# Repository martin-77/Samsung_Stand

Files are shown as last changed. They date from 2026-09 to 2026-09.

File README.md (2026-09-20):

# Samsung_Stand

Parametric, test-driven CAD project for a modular PETG adapter that reuses the original Samsung UE55J6250 stand on a Magnat Sounddeck 150 and adds limited swivel.

## Design targets

- Reuse the original Samsung stand assembly.
- Magnat Sounddeck 150 footprint: **700 × 340 mm**.
- Working Samsung stand-only footprint: **840 mm width** and ~**288 mm reconstructed depth**; both remain subject to physical stand measurement. Samsung separately specifies the complete UE55J6250 **TV+stand envelope** as 1230.6 × 770.6 × 310.5 mm, which must not be confused with the stand-only footprint.
- Printer target: **Prusa CORE One L, 300 × 300 × 330 mm**.
- Material target: PETG.
- Modular printed construction with form-locking joints; snap tabs are retention only, never primary structural load paths.
- Large fixed base on the Sounddeck.
- Central swivel with limited range, initially **±15°**.
- Inner saddle/support points carry vertical load inside the Sounddeck footprint.
- Outer printed rails guide the original Samsung stand but should not become long vertical-load cantilevers.
- No CAD change is considered valid until geometry/layout checks pass.

## Engineering approach

This repository follows the test-driven CAD approach used in `martin-77/eurobox`:

1. Keep dimensional truth in code.
2. Validate global assembly geometry independently from local CAD construction.
3. Hard-gate print-bed limits, support-point position, swivel sweep, clearances and exported meshes.
4. Generate CAD/STL only from the validated parameter set.
5. Treat inferred dimensions separately from verified dimensions.

## Current baseline

Initial working geometry:

- Sounddeck: 700 × 340 mm
- Fixed base target: 680 × 295 mm
- Samsung stand width: 840 mm
- Samsung stand-only reconstructed depth: ~288 mm (unverified)
- Samsung complete TV+stand depth: 310.5 mm (manufacturer-verified envelope, not stand-only footprint)
- Pivot offset: 64 mm rearward from Sounddeck center
- Inner load/saddle stations: x ≈ ±250 mm along the reconstructed arm geometry
- Saddle orbit radius: ~279 mm
- Swivel target: −15° / 0° / +15°

See `docs/DESIGN_BASELINE.md` and the geometry validation scripts before changing these values.

## Current status

The repository has progressed to **v8** as the validated structural geometry candidate, plus a measurement-driven contact-generation pipeline:

- v1: modular three-piece fixed base and central annular swivel bearing;
- v2: dual-load-path INNER_ARM with rotor root landing and side glide tracks;
- v3: modular OUTER_GUIDE rails, intentionally non-load-bearing vertically;
- v4: calibrated positive mechanical +/-15 degree end stops plus complete carrier sweep clearance;
- v5: replaceable zero-position PETG detent cassette with 1.8 / 2.2 / 2.6 mm calibration variants;
- v7: replaceable 1.2 mm PETG center-bearing and side-track wear surfaces while preserving the validated z=10 / z=18 support planes;
- v8: fully assembled transverse PETG retention: four above-base module pins, two ROTOR/INNER pins, two externally accessible INNER/OUTER pins and one positive pivot cross-pin in a top-open rotor chamber;
- measured-contact pipeline: provenance-gated physical measurement model, three-section root/center/tip saddle lofts per side, and four independent lateral-only OUTER_GUIDE side rails;
- proof-load tooling: two flat saddle-pocket inserts that apply the 500 N structural substitute load at the validated support stations on a rigid surrogate support, not on the Sounddeck;
- release-validation pipeline: a machine-checkable physical test record that verifies the user-declared proof, creep, cycling, fit-coupon and Sounddeck-interface criteria.

For v8 the parameter gates, FreeCAD build, watertight-mesh checks and installed
OCC collision/contact checks are green. All replacement retainers are checked in
their actual installed positions. The pivot lock preserves the full +/-15 degree
rotation with 0.7 mm intentional axial lift clearance and positively blocks
further lift. The +/-15 degree end stops remain structural; the center detent is
positional only.

The v6 measurement-to-CAD path is also green against a synthetic CI fixture:
measurement validation, FreeCAD generation, watertight-mesh gates and installed
contact-part checks against the current v8 structural STEP geometry all pass.
All six measured saddle sections (left/right root/center/tip) are checked at
their exact YZ station for surface contact with **0 mm² section penetration**;
the load-bearing loft is limited to 25 mm maximum measured-section spacing and
8 mm maximum endpoint extrapolation. OUTER_GUIDE root/mid/tip profiles are
checked at 0.5 mm nominal
lateral clearance and at their measured common-datum vertical positions. The
minimum real guide-floor clearance is therefore derived from measurements rather
than assumed to be 9 mm. The outer contact parts
are four independent side rails with no generated floor bridge.
Production v6 contact parts remain intentionally unpublished until
`measurements/stand_measurements.json` contains complete measurements marked
`measurement_kind: physical`; synthetic CI data are hard-rejected by the
production validator and builder.

This is **not yet a physical structural release for mounting the TV**.  The
Samsung arm contact geometry is still based partly on reconstruction and must be
measured before final saddle/guide inserts are generated.  A real fit-coupon
sequence and non-fragile proof-load test are required before TV use.

See:

- `cad/v8/` for the newest validated structural CAD candidate;
- `cad/fit_coupons/` for roof-key clearance coupons;
- `cad/retainer_coupons/` for v8 snap-pin / pivot-pin fit coupons;
- `cad/detent_coupon/` for the zero-detent calibration rig;
- `cad/proof_load_fixture/` for the validated substitute-load saddle pads;
- `docs/ASSEMBLY_V8.md` for the practical v8 assembly order;
- `measurements/` and `docs/REQUIRED_MEASUREMENTS.md` for the remaining physical dimensions and profile capture;
- `docs/PHYSICAL_RELEASE_GATES.md` for fit, anti-slip, creep and proof-load release gates;
- `release_validation/physical_release.template.json` plus `scripts/validate_physical_release.py` for the recorded final physical gate.

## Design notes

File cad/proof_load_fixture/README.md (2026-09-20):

# V8 proof-load saddle pads

Print 2x proof_load_saddle_pad.

They seat in the two validated INNER_ARM saddle pockets and stand 3 mm
above the arm top plane. Place a rigid flat spreader board across both
pads so the test load enters at the real saddle stations.

Requirements:
- support the complete adapter on a rigid flat surrogate surface;
- do not use the Magnat Sounddeck as the 500 N proof support;
- the spreader must touch only the two proof pads;
- use a non-fragile substitute load, never the TV;
- test 500 N at center, -15 deg and +15 deg;
- additionally test each saddle branch alone at at least 250 N;
- follow docs/PHYSICAL_RELEASE_GATES.md for dwell, inspection and
  release criteria.

These pads are test tooling, not final Samsung contact parts.

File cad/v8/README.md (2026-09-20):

# Samsung Stand v8

v8 replaces the previously unproven retainer concepts with explicitly assembled and OCC-validated PETG retention.

Changes:
- 4 horizontal snap pins lock BASE_LEFT/RIGHT to BASE_CENTER entirely above the Sounddeck plane;
- 2 compact snap pins lock ROTOR to the two INNER_ARM parts;
- 2 longer snap pins pass completely through the INNER_ARM saddle region and lock the OUTER_GUIDE parts from an externally accessible side;
- the fixed pivot post is extended and cross-drilled with a support-free roof tunnel;
- 1 pivot cross-pin sits inside a circular rotor counterbore and positively limits axial lift while preserving rotation.

Removed from the v8 print list:
- legacy vertical base retainers;
- legacy pivot C-clip;
- legacy v2 arm lock pin.

The v7 replaceable wear surfaces and v5 detent/end-stop architecture remain upstream.

Geometry validation is not physical structural release. Fit/proof/cycling gates in docs/PHYSICAL_RELEASE_GATES.md still apply.

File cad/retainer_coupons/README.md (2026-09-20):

# V8 retainer fit coupons

Print these before the large v8 modules.

Three exact geometry families are included:
- base receiver + compact joint pin;
- 58 mm outer/saddle receiver + long outer pin;
- Ø25 mm pivot post + pivot cross-pin.

Acceptance:
- insert by hand without hammering;
- no crack or visible PETG whitening;
- barb snaps fully beyond the far wall;
- light manual pull does not release it;
- split legs can be compressed for non-destructive removal;
- no obvious permanent set after several insertion/removal cycles.

These coupons calibrate printed retention fit only. They do not replace the full assembly proof-load and cycling gates.

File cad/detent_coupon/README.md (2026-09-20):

# Zero-detent calibration rig

Compact rig using the exact v5 cam track and replaceable detent cassette geometry.

Print:
- 1x detent_coupon_base
- 1x detent_coupon_cam
- 2x detent_coupon_pin
- initially 1x detent_coupon_cassette_t18

If t18 does not reliably re-center, try t22, then t26.

Reject a variant if it shows whitening, excessive breakaway torque,
permanent set, rough stick-slip, or rapid wear.

This rig calibrates detent feel only. It is not a structural proof-load fixture.

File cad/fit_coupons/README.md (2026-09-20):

# Structural fit coupons

These small coupons calibrate the three form-locking roof-key joints before large PETG parts are printed.

Families:
- base: BASE_LEFT/RIGHT into BASE_CENTER;
- inner: INNER_ARM into ROTOR;
- outer: OUTER_GUIDE into INNER_ARM.

For each family print:
- one male probe;
- c030 receiver: 0.30 mm nominal clearance;
- c040 receiver: 0.40 mm nominal clearance;
- c050 receiver: 0.50 mm nominal clearance.

The current production CAD uses 0.40 mm nominal side/roof clearance.

Selection rule:
use the smallest receiver that slides fully onto the probe without force, binding or visible PETG whitening, while still avoiding obvious rocking.

These coupons test cross-sectional printer/material fit. They do not replace the later full-joint or proof-load test.

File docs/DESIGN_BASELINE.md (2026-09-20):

# Design baseline

## Scope

Adapter system for a Samsung UE55J6250 using the original wide Samsung stand on a Magnat Sounddeck 150.

The design must be printable on a Prusa CORE One L and assembled from multiple PETG parts using form-locking joints plus replaceable snap retainers.

## Confidence levels

### Verified / high confidence

- Samsung UE55J6250 weight with stand: 16.7 kg.
- Samsung UE55J6250 complete envelope with stand: 1230.6 × 770.6 × 310.5 mm.
- Samsung UE55J6250 body depth without stand: 64.0 mm.
- Samsung's specified stand swivel: 0°.
- Magnat Sounddeck 150 footprint: 700 × 340 mm.
- Samsung stand family/base width used as working source dimension: 840 mm.
- Prusa CORE One L build volume: 300 × 300 × 330 mm.

### Reconstructed / must be physically verified before final release

- Pure stand-only depth: approximately 288–290 mm as a reconstruction only.
  Samsung's verified 310.5 mm value is the **complete TV+stand depth**, so it
  cannot be substituted for this stand-only measurement.
- Stand-arm planform and arm centerline.
- Pivot-to-rear stand contour: approximately 80 mm.
- Pivot-to-front stand tip: approximately 208 mm in Y with ±420 mm X tip coordinates.
- Stand-arm cross-section along the guide rails.

These inferred values may be used for layout and collision exploration, but **must not silently become manufacturing truth**.

## Coordinate system

- X: left/right, Sounddeck center at x = 0.
- Y: front/back, positive Y = front.
- Z: upward.
- Sounddeck geometric center = (0, 0).
- Initial swivel axis = (0, -64 mm), i.e. 64 mm rearward from Sounddeck center.

## Magnat Sounddeck interface constraints

Manufacturer documentation explicitly describes the Sounddeck 150 as suitable
for placement directly below a television and states that the enclosure is
designed to carry a small-to-medium TV. The front speaker systems and display are
on the front face; the subwoofer is down-firing. The rear amplifier cooling
plate / cooling openings must remain unobstructed.

Project consequences:

- the adapter remains entirely on the 700 × 340 mm top surface;
- the 680 × 295 mm fixed base is centered and therefore leaves 22.5 mm top-edge
  margin at both front and rear;
- future base-depth changes must preserve at least 20 mm front/rear top-edge
  margin;
- no printed part may wrap around or cover the rear amplifier/cooling panel;
- the Sounddeck must itself remain on the solid, level support required for the
  down-firing subwoofer.

Primary source:
- Magnat Sounddeck 150 manual, installation/safety section and illustrations.

## Fixed base

Target fixed base footprint:

- width: 680 mm
- depth: 295 mm
- centered in X
- kept fully inside the 700 × 340 mm Sounddeck footprint

The base will be split into printable modules. The central swivel-bearing region must remain on one unbroken center module.

## Load path

Nominal static weight force:

- 16.7 kg × 9.81 m/s² ≈ 164 N

Initial engineering design load for geometry and structural development:

- 500 N vertical

This is an internal design target, not a certified safety factor.

Primary vertical load path:

1. original Samsung stand
2. two broad inner PETG saddles
3. upper rotating carrier
4. broad glide/support pads on circular paths
5. fixed base
6. Magnat Sounddeck

The outer rails primarily provide lateral guidance and anti-twist support.

They must **not** be treated as long primary vertical-load cantilevers.

## Samsung envelope versus reconstructed stand planform

Samsung's model-specific Quick Guide BN68-07177M-00 specifies the complete
UE55J6250 assembly with stand at **1230.6 × 770.6 × 310.5 mm** and lists
**Stand Swivel (Left / Right): 0°**. The TV body itself is only 64.0 mm deep.

Consequences:

- 310.5 mm is a hard external-envelope reference for the original assembled TV;
- it is **not** a direct measurement of the stand-only footprint;
- the current ~288 mm stand-only reconstruction therefore remains an assumption
  until the real stand is measured;
- our ±15° mechanism rotates the complete TV + original stand together beneath
  the OEM stand, so it does not twist Samsung's non-swivelling TV-to-stand
  connection.

Primary source: Samsung Quick Start Guide BN68-07177M-00
(`UJ6250-ZG_BN68-07177M-00L04-0331.pdf`), UE55J6250 / UE55J6270
specification table.

## Reconstructed stand planform

Current working tip coordinates relative to swivel axis:

- left tip: (-420, +208) mm
- right tip: (+420, +208) mm
- approximate rear contour: y = -80 mm

This corresponds to an arm centerline slope of 208 / 420.

## Inner saddles

Initial support station:

- x = ±250 mm
- y = 250 × (208 / 420) ≈ 123.8 mm relative to swivel axis
- support orbit radius ≈ 279 mm

The saddle/support pad footprint must remain inside the Sounddeck at all allowed swivel angles.

## Swivel

Initial allowed range:

- -15°
- 0°
- +15°

The outer Samsung stand tips are allowed to overhang the Sounddeck.

The **load supports are not**.

Future CAD must include:

- positive end stops
- center detent
- optional ±15° detents
- cable-safe limited rotation
- large-area PETG-on-PETG bearing surfaces
- central axis used primarily for guidance, not as the only vertical load path

## Modular print architecture

Target module classes:

- BASE_CENTER
- BASE_LEFT
- BASE_RIGHT
- ROTOR
- INNER_LEFT
- INNER_RIGHT
- OUTER_GUIDE_LEFT
- OUTER_GUIDE_RIGHT
- replaceable RETAINER clips

Rules:

- no structural module may exceed the 300 × 300 mm XY build limit
- preferred maximum XY envelope for large parts: 295 × 295 mm
- snap tabs retain joints; they do not carry the primary bending/shear load
- structural joints use long overlap / dovetail / trapezoidal form locking
- retainers should be replaceable without reprinting a major module

## Required hard gates before printable release

- global dimensions are internally consistent
- fixed base remains within Sounddeck footprint
- support points remain within Sounddeck footprint across full swivel range
- support pads retain edge margin across full swivel range
- all printable modules fit the printer build volume
- exported meshes are watertight and have positive volume
- assembled left/right geometry is mirrored correctly
- no accidental load path through only snap tabs
- guide rails have explicit clearance and do not unintentionally preload the original stand

## Verified service load

Samsung's Quick Start Guide BN68-07177M-00 lists the UE55J6250 at 16.7 kg with
its original stand. Using standard gravity, the static service load is therefore
approximately 163.8 N.

The project's 500 N vertical design load is an internal adapter-development
load, approximately 3.05 times the real static TV weight. It is **not** a
certified safety factor and must not be interpreted as permission to place a
500 N proof load on the Magnat Sounddeck itself.

Physical release therefore separates:

- adapter structural proof: 500 N on a rigid flat surrogate support;
- real Sounddeck interface test: approximately the real 163.8 N TV service
  load, with a validator ceiling of 110% for the interface test.

Source: Samsung Quick Start Guide BN68-07177M-00, model table for
UE55J6250 / UE55J6270.

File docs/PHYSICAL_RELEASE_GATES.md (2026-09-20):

# Physical release gates

The generated CAD is test-driven for geometry, assembly, print envelope and
collision behavior. That is not the same as a verified structural release for
a television.

A version may be marked **printable candidate**, but not **physically released**,
until all gates below are completed on the real hardware and recorded.

## 1. Real Samsung stand geometry

Still required:

- stand-arm cross-sections at inner-saddle root / center / tip on both sides;
- stand-arm cross-section / side profile at outer-guide root / mid / tip;
- actual stand depth and rear contour;
- verification that the reconstructed pivot/arm centerline matches the physical
  stand closely enough over the complete +/-15 degree sweep.

The structural CAD deliberately isolates these unknowns:

- the inner support uses a replaceable saddle insert;
- the outer U-guide remains an oversized structural guide until four
  lateral-only side rails (negative-Y and positive-Y per guide) are generated
  from physical measurements. No generated outer contact part may bridge below
  the Samsung arm or become a normal vertical support.

Do not convert reconstructed dimensions into manufacturing truth by assumption.

## 2. Fit coupons before full print

Print small fit coupons before the large structural modules:

1. base roof-key + receiver clearance coupon;
2. rotor/INNER_ARM roof-key + cross-pin coupon;
3. INNER_ARM/OUTER_GUIDE roof-key + cross-pin coupon;
4. final Samsung saddle insert;
5. final measured OUTER_GUIDE side-rail fit (all four rails);
6. selected zero-detent spring cassette;
7. v8 base-joint transverse retainer coupon;
8. v8 long INNER_ARM/OUTER_GUIDE retainer coupon;
9. v8 pivot-post / cross-pin retainer coupon.

Record printer, material, nozzle, layer height and actual measured clearances.

### Measured-contact dry fit

Before any proof load, install the **real original Samsung stand** into the
generated PETG contact parts without the television and verify the complete
contact path.

For each left/right saddle insert:

1. confirm seating/contact at the measured **root, center and tip** sections;
2. check that the stand does not rock when alternately pressed near the root and
   tip of the saddle region;
3. check for a local high spot that prevents another measured section from
   seating;
4. inspect the unmeasured intervals between the three sections for unexpected
   bosses, ribs or curvature that the loft could not know from the measurements.

For each OUTER_GUIDE:

1. confirm all four side rails sit fully down on the guide floor before the
   original stand is inserted;
2. confirm the side rails guide the real arm without binding;
3. confirm visible/free vertical clearance below the arm;
4. specifically verify that the arm does **not** touch the structural guide
   floor anywhere through the guide span.

These observations are separate fields in the physical release record. A generic
"dry fit passed" is not sufficient by itself.

## 3. Static proof loading

The geometry model uses a 500 N vertical engineering design load. The verified
Samsung UE55J6250 mass with original stand is 16.7 kg, corresponding to about
163.8 N static service load. Thus 500 N is roughly 3.05 times the real static
TV load. This remains an internal development target, not a certified load
rating or safety factor.

Before mounting the TV, assemble the complete adapter on a **rigid, flat
surrogate support**, not on the Magnat Sounddeck, and apply a non-fragile
substitute load at the real Samsung support locations.

The repository provides `cad/proof_load_fixture/proof_load_saddle_pad`.
Print two pads and place one in each INNER_ARM saddle pocket. A rigid flat
spreader board may then bridge only those two pads so the substitute load enters
at the validated saddle stations without using the television or the
OUTER_GUIDE parts as load supports.

Do **not** use the real Sounddeck as the 500 N proof fixture. The 500 N value is
an adapter development load. Magnat's manual states that the Sounddeck is
intended to carry a small-to-medium television but does not provide a numeric
maximum load in the manual. The Sounddeck interface is tested separately at
approximately the verified real TV service load.

Minimum test sequence on the rigid surrogate support:

1. preload / settle the assembly;
2. apply the full 500 N load in center position;
3. apply the full 500 N load at -15 degrees;
4. apply the full 500 N load at +15 degrees;
5. test the left saddle branch alone at at least 250 N;
6. test the right saddle branch alone at at least 250 N;
7. hold every test case for the declared minimum dwell time;
8. unload and inspect after each case;
9. repeat the swivel cycle and check that the zero detent and positive end stops
   still behave normally.

The two one-side cases are intentional. They verify each nominal 250 N branch
independently and can expose asymmetric print, seating or assembly defects that
a symmetric spreader-board test could hide.

Record:

- applied load;
- duration;
- permanent deformation after unload;
- cracks / whitening / layer separation;
- loosened retaining pins;
- change in swivel friction;
- change in detent feel;
- any base movement on the Sounddeck;
- visible marking / indentation of the Sounddeck top surface;
- whether the replaceable wear inserts remain seated;
- whether any V6 OUTER_GUIDE side rail has lifted from its seat;
- whether any V6 OUTER_GUIDE side rail has moved axially past its intended
  root/tip capture position.

The eventual proof-load magnitude and duration must be chosen deliberately
before calling the design structurally released. The current CAD repository does
not claim a certified safety factor.

## 4. End-stop verification

The v4+ CAD has positive mechanical +/-15 degree end stops. OCC validation proves
geometric contact behavior, but the printed stop must also be checked for:

- no brittle impact damage;
- no layer splitting at the rotor stop spoke;
- no deformation of the fixed stop towers;
- continued operation after repeated gentle end-stop contacts.

Do not use the detent cassette as an end stop.

## 5. Detent calibration

The v5 detent is intentionally replaceable. The 1.8 / 2.2 / 2.6 mm spring
variants are calibration choices, not validated force specifications.

Select the lowest spring force that reliably centers the stand without causing:

- excessive breakaway torque;
- visible spring whitening;
- permanent set;
- noisy stick-slip;
- accelerated wear on the rotor cam.

## 6. Static stability characterization and anti-tip restraint

The UE55J6250 Quick Guide BN68-07177M-00 warns that pulling or pushing the TV can
cause it to tip and describes a wall anti-fall restraint for added stability.
This project adds a raised, rotating support underneath the complete original
stand, so the physical release is intentionally stricter: an anti-tip restraint
is required for the final installation.

This is **not** a claim that Samsung specifies a numeric horizontal test force
for this adapter. No such value is invented here.

### Sounddeck flat-area measurement

Before interpreting the 680 × 295 mm base as the real support polygon, measure
the actually flat top surface of the Sounddeck:

- usable flat width;
- usable flat front-to-rear depth;
- whether every point of the printed base is supported by the flat region;
- whether any base edge sits on a radius, chamfer or rounded cabinet edge.

The current 20 mm nominal top-edge margin is a project assumption, not a Magnat
load-rating requirement. These measurements determine whether a future deeper
base is physically possible.

### Fore/aft centre-of-gravity characterization

Use two rigid transverse load-spreading bars or equivalent full-width reaction
lines underneath the **complete final TV + adapter assembly** on a rigid test
surface. Do not perform this measurement on two isolated point supports that can
twist the base.

Record the Y position of the rear and front reaction lines relative to base
centre, then record rear/front reaction force at:

1. -15°;
2. 0°;
3. +15°.

Also record the vertical reference height at which an idealized horizontal force
is to be characterized. The validator calculates:

- total measured reaction;
- projected Y centre of gravity;
- static distance to rear and front base edges;
- idealized horizontal force at the chosen height that would balance the static
  gravity moment about each edge.

The last values are **characterization only**. They are not a certified tipping
load and do not create an acceptance threshold. The validator does require
positive reactions, a centre-of-gravity projection inside the base, and less
than 5% change in total measured reaction between swivel positions so gross
measurement/setup errors are caught.

### Anti-tip restraint

Use the anti-fall concept described in Samsung Quick Guide BN68-07177M-00 with
hardware and wall anchorage appropriate to the actual wall. The release record
requires confirmation that:

- the restraint is installed;
- wall anchorage is verified;
- TV-side attachment is verified;
- the complete -15° to +15° swivel range works without binding or forcing the
  restraint;
- the restraint is not loose, damaged or interfering with normal swivel.

This is an additional safety layer; it does not compensate for a geometrically
unstable base.

## 7. Sounddeck interface / anti-slip gate

The adapter is intentionally all-PETG at this stage. That means sufficient
friction against the real Magnat top surface must be **measured**, not assumed.

Before mounting the TV:

1. place the complete unloaded adapter on the real Sounddeck;
2. mark its centered position;
3. apply the expected hand torque needed to move through the detent and the
   complete +/-15 degree swivel range;
4. add a non-fragile substitute load of at least the verified TV service load
   (16.7 kg with stand, approximately 163.8 N) but no more than 110% of that
   load for this interface test;
5. repeat the swivel / detent operation;
6. verify that the rotating assembly moves while the fixed 680 x 295 mm base
   does not translate or yaw on the Sounddeck;
7. inspect the Sounddeck finish for scratches, pressure marks or local
   indentation.

The 500 N structural proof belongs on the rigid surrogate support, not here.

If the fixed base moves, the all-PETG interface is not released. Do not simply
increase detent force. The correction must reduce required swivel torque or add
a separately justified locating / friction concept without concentrating the TV
load onto small points.

## 8. Creep / dwell gate

Short OCC/static checks do not validate long-term PETG creep.

Before final release, the complete printed load path must be held under a
representative sustained substitute load long enough to detect meaningful
settling at:

- the center wear ring;
- both side wear arcs;
- INNER_ARM root landings;
- saddle inserts;
- form-locking base joints;
- pivot post / cross-pin retention.

Record initial and final heights / gaps at defined reference points and repeat
the swivel test after unloading. Any progressive permanent set, growing joint
play or whitening is a failed gate.

## 9. Release criterion

A physically released version needs all of the following:

- CAD design gates green;
- measured Sounddeck flat area fully supports the fixed base;
- final assembly stability characterized at -15° / 0° / +15°;
- anti-tip restraint installed and verified through the full swivel range;
- final STL mesh gates green;
- installed OCC assembly gates green;
- real stand geometry measured and final contact inserts generated;
- roof-key, retainer and detent fit coupons passed on the target printer/material;
- full assembly printed;
- Sounddeck anti-slip / surface-protection gate passed;
- physical static proof test passed;
- sustained creep / dwell gate passed;
- swivel/end-stop cycling passed;
- chosen detent cassette passed physical calibration;
- photographs and measured results committed under a release-validation folder.

Record the physical result in a copy of
`release_validation/physical_release.template.json` named
`release_validation/physical_release.json`. The declared dwell durations and
cycle counts must be chosen before the test and explained in the record. CI then
runs `scripts/validate_physical_release.py` and checks the recorded outcomes
against those declared criteria. The 500 N development load remains the only
hard-coded proof-load floor; passing the validator is not a certification or
independent safety approval.

Until then, the newest CAD version is a validated **geometry candidate**, not a
verified structural product.

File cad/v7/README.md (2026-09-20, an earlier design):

# Samsung Stand v7

v7 adds replaceable flush PETG wear surfaces without changing the validated v5 geometry planes.

Added service parts:
- 1x center wear ring, 1.2 mm thick;
- 2x universal side-track wear arcs, 1.2 mm thick.

The fixed base receives shallow recesses. Installed wear pieces restore:
- center bearing top to the original z=10 mm plane;
- side glide-track top to the original z=18 mm plane.

The rotor, INNER_ARM, OUTER_GUIDE, end stops and detent geometry remain at their v5 positions.

Purpose:
normal PETG-on-PETG sliding wear is moved onto cheap replaceable parts rather than the large structural modules.

This remains a geometry candidate until the physical release gates are completed.

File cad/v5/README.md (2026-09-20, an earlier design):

# Samsung Stand v5

v5 adds a replaceable zero-position detent calibration cassette to the validated v4 structure.

Architecture:
- only 0 degrees is detented;
- +/-15 degrees remain positive structural end stops from v4;
- the rotor carries a flat cam sector with a shallow V-notch at zero;
- a fixed, replaceable PETG cantilever cassette engages that track;
- the cassette is printed flat so the spring bends in the XY plane;
- two removable locating pins retain the cassette on a fixed platform.

Calibration variants:
- t18: 1.8 mm spring thickness;
- t22: 2.2 mm spring thickness;
- t26: 2.6 mm spring thickness.

The beam strain estimates are geometric only. The documented force ranges use a broad nominal PETG modulus range and are not treated as measured print behavior. Print one calibration variant first before choosing the final detent feel.

v5 re-validates the v4 mechanical end stops after adding the cam and fixed mount.

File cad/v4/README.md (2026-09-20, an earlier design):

# Samsung Stand v4

v4 extends the validated v3 assembly with positive mechanical +/-15 degree swivel end stops.

Stop architecture:
- a flat-printable spoke and broad stop tab are fused into the rotor;
- two broad fixed stop towers are fused into BASE_CENTER;
- BASE_CENTER has a narrow sweep-clearance corridor above the bearing plane so the stop can start at rotor-local Z=0 without support;
- the mechanical stop carries end-stop load. A later detent, if added, is positional only.

Validation contract:
- at +/-14 degrees the stop must remain free;
- at +/-15 degrees the stop must be surface contact without meaningful penetration;
- at +/-15.5 degrees the stop must show solid interference, proving positive blocking;
- the full rotating carrier is collision-checked against the fixed base through representative sweep positions.

The Samsung arm contact channel remains a measured-fit TODO; v4 does not change the v3 placeholder fit claim.

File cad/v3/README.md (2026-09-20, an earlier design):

# Samsung Stand v3

v3 extends the validated v2 rotating load path with modular outer guide rails.

Structural concept:
- INNER_ARM remains the vertical load carrier between rotor/root landing and the side glide track.
- OUTER_GUIDE plugs into the end of INNER_ARM with a 45-degree roof key.
- The same replaceable transverse PETG snap pin can retain the outer joint.
- OUTER_GUIDE has positive clearance to the fixed base and is intentionally not a normal vertical support.
- The U-shaped rail reaches beyond the reconstructed Samsung foot tip.

Current fit limitation:
- the U-channel is deliberately oversized (60 mm internal placeholder width).
- exact Samsung arm side/cross-section geometry still requires physical measurement.
- no claim is made that the placeholder channel is the final press/slide fit.

Suggested print quantities are stored in VALIDATION_v3_source.json.

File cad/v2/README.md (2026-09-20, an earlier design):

# Samsung Stand v2

Validated second structural increment built on the published v1 STEP baseline.

Added:
- annular-sector glide tracks on the fixed left/right base modules;
- track top coplanar with the installed rotor top;
- two form-locking rotor receivers;
- one universal INNER_ARM printed twice;
- replaceable transverse PETG snap-lock pin;
- replaceable saddle cartridge.

Load-path intent:
- central load enters the rotor through its broad annular support;
- each inner arm is supported at its root by the rotor and near the real load station by its own side glide track;
- the inner arm is therefore not treated as a long cantilever from the center.

Important unresolved manufacturing input:
- the exact Samsung stand-arm cross-section is not inferred into the structural part.
  samsung_stand_v2_saddle_insert_blank is intentionally only a calibration blank.
  The final contact insert will be generated after physical cross-section measurements.

OUTER_GUIDE parts and final swivel detents/end-stops are not part of v2 yet.

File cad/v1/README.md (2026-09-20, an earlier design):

# Samsung Stand v1

First validated structural CAD increment.

Included:
- three-piece 680 × 295 mm fixed base;
- two support-friendly 50 mm roof-key joints per side;
- replaceable PETG snap retainer pin;
- Ø150 / Ø80 mm annular swivel load path;
- central guide pilot plus removable PETG C-clip;
- rotor core prepared for later left/right saddle carriers.

Not included yet:
- final Samsung arm cross-section;
- INNER_LEFT / INNER_RIGHT saddle carriers;
- OUTER_GUIDE_LEFT / OUTER_GUIDE_RIGHT;
- final detent and ±15° stop mechanism.

The original Samsung stand outline in the preview is reconstructed reference geometry only, not manufacturing truth.

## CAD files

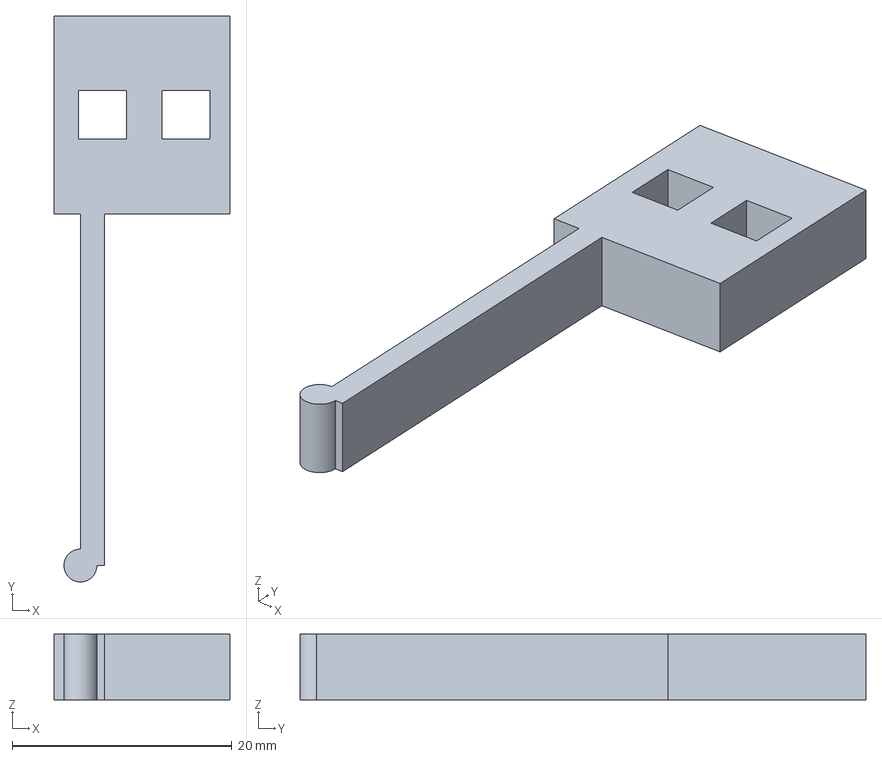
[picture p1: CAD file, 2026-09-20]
cad/detent_coupon/STEP/detent_coupon_cassette_t22.step
16.0 x 51.5 x 6.00 mm

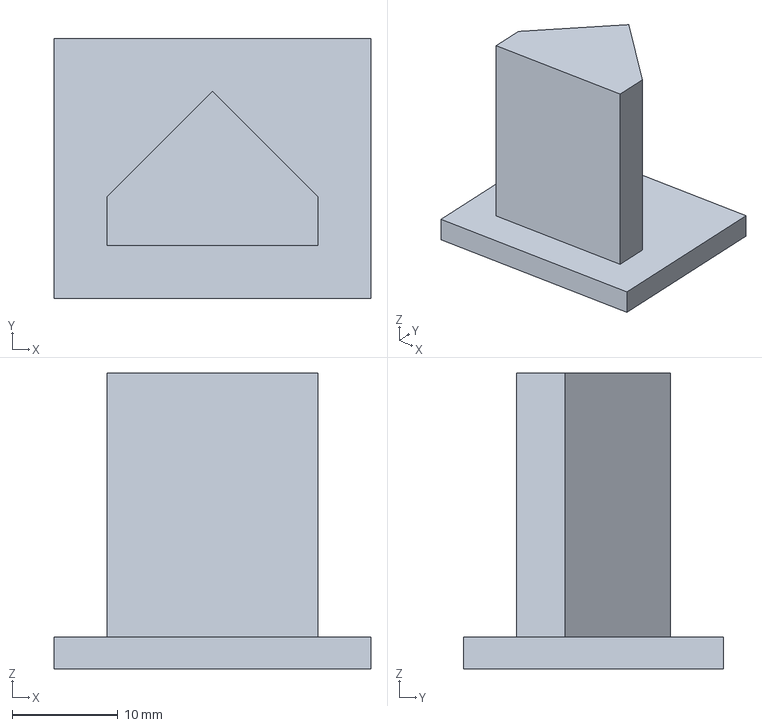
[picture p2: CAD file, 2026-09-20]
cad/fit_coupons/STEP/fit_inner_male_probe.step
30.0 x 24.6 x 28.0 mm

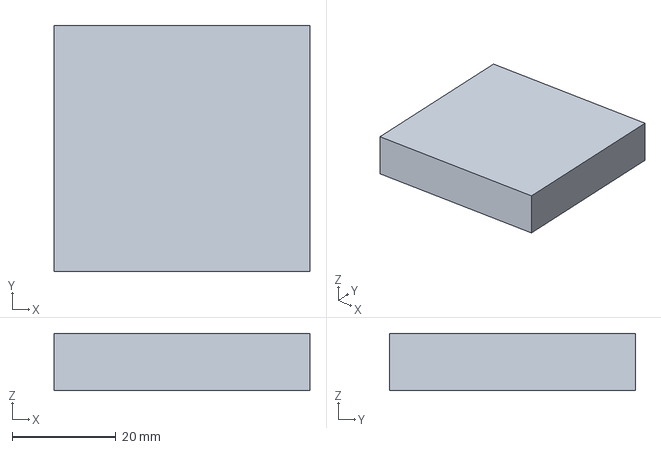
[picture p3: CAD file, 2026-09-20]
cad/proof_load_fixture/STEP/proof_load_saddle_pad.step
49.4 x 47.4 x 11.0 mm

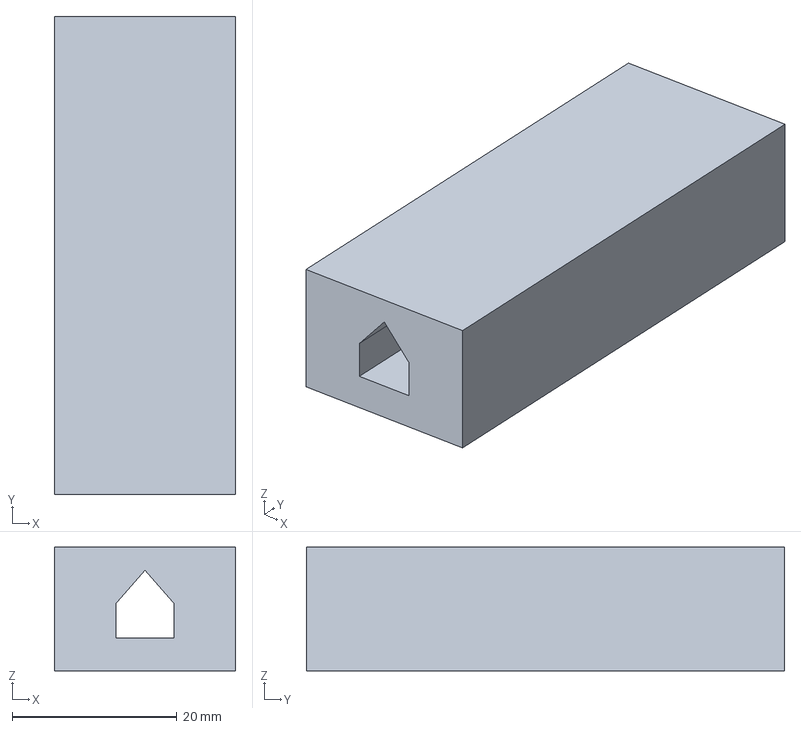
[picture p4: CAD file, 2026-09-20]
cad/retainer_coupons/STEP/retainer_coupon_outer_receiver.step
22.0 x 58.0 x 15.0 mm

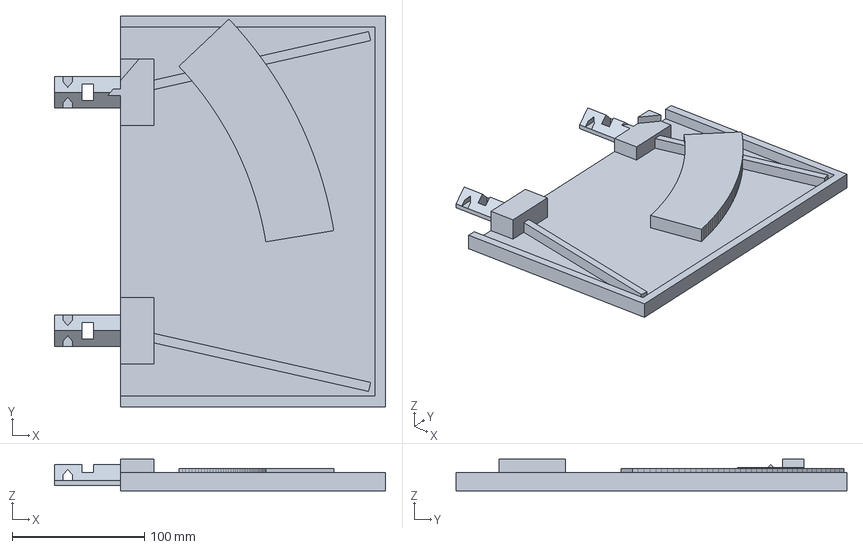
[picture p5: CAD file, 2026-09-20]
cad/v8/STEP/samsung_stand_v8_base_right.step
250.0 x 295.0 x 24.0 mm

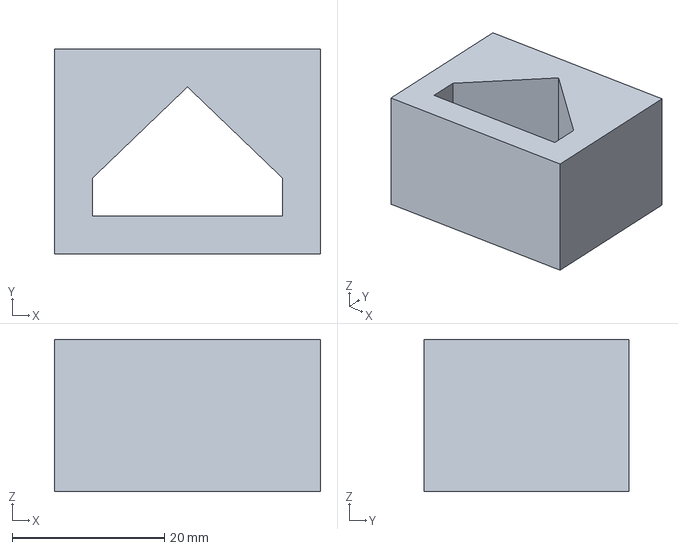
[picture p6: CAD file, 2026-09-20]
cad/fit_coupons/STEP/fit_base_receiver_c050.step
35.0 x 27.0 x 20.0 mm

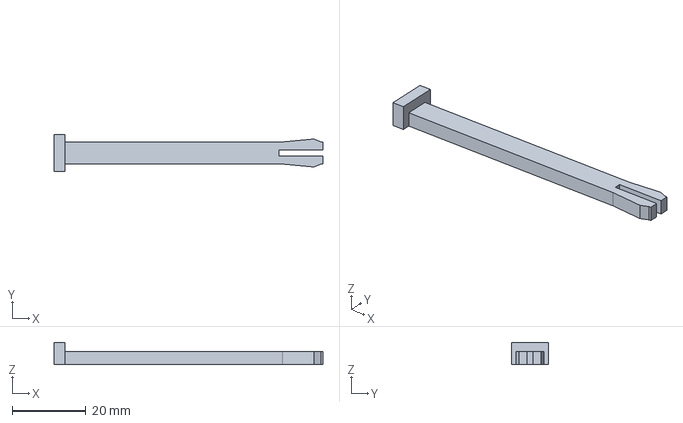
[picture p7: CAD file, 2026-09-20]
cad/retainer_coupons/STEP/retainer_coupon_outer_pin.step
73.0 x 10.0 x 6.00 mm

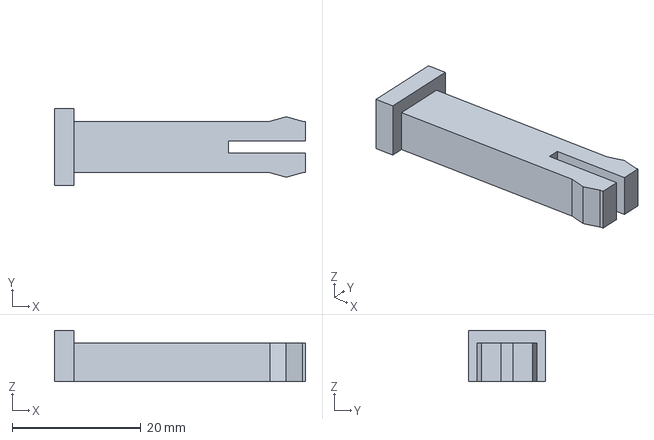
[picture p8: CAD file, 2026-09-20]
cad/v8/STEP/samsung_stand_v8_pivot_lock_pin.step
39.0 x 12.0 x 8.00 mm

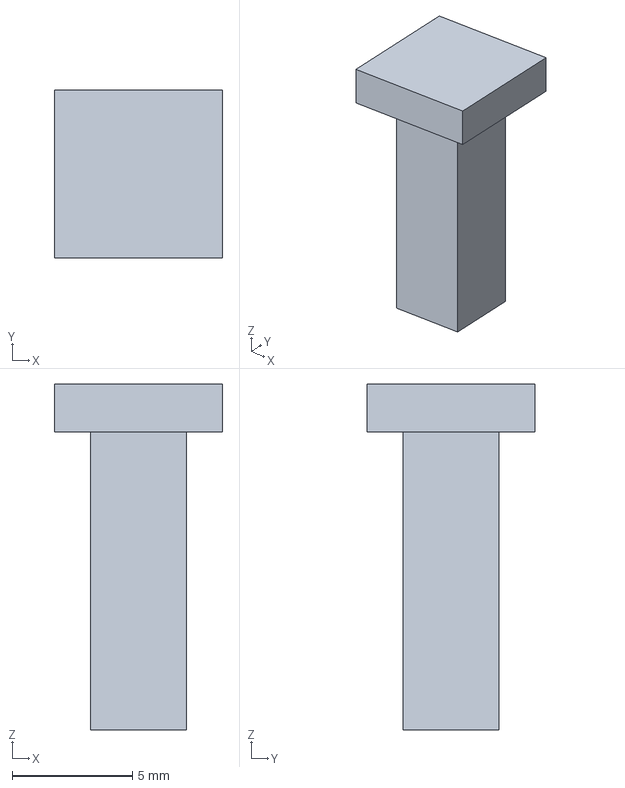
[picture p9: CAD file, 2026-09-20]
cad/detent_coupon/STEP/detent_coupon_pin.step
7.00 x 7.00 x 14.4 mm

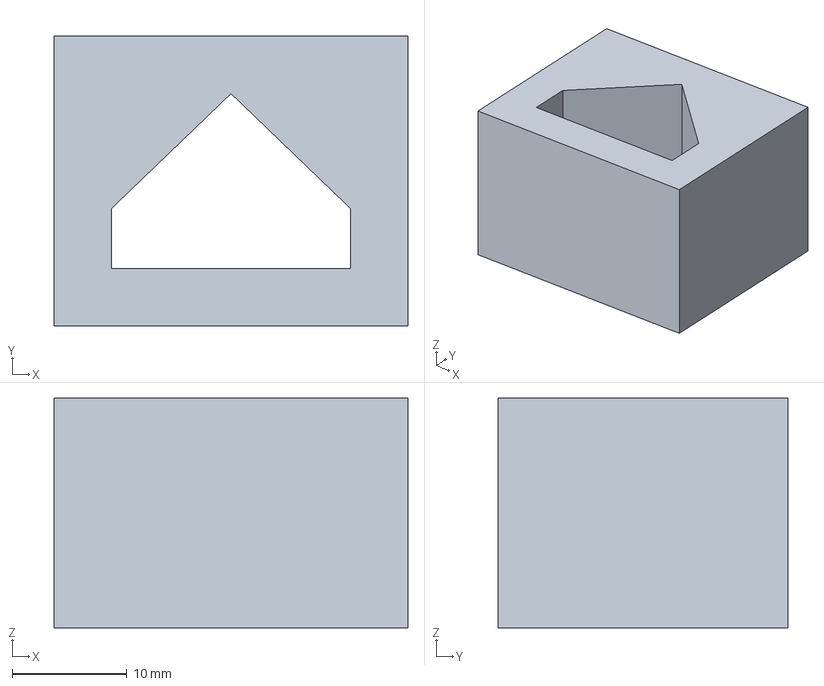
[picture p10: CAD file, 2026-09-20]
cad/fit_coupons/STEP/fit_inner_receiver_c040.step
30.8 x 25.2 x 20.0 mm

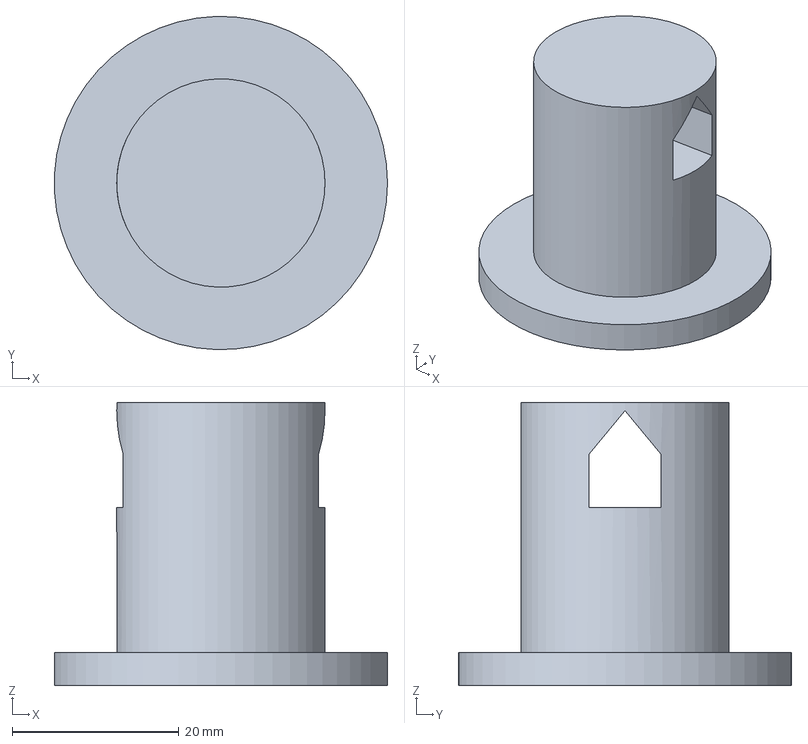
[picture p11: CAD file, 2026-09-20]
cad/retainer_coupons/STEP/retainer_coupon_pivot_post.step
40.0 x 40.0 x 34.0 mm

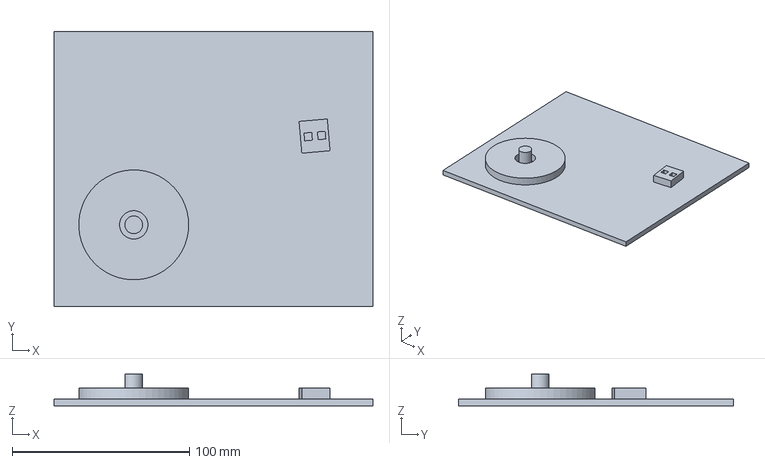
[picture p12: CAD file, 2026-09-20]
cad/detent_coupon/STEP/detent_coupon_base.step
180.0 x 155.0 x 18.0 mm

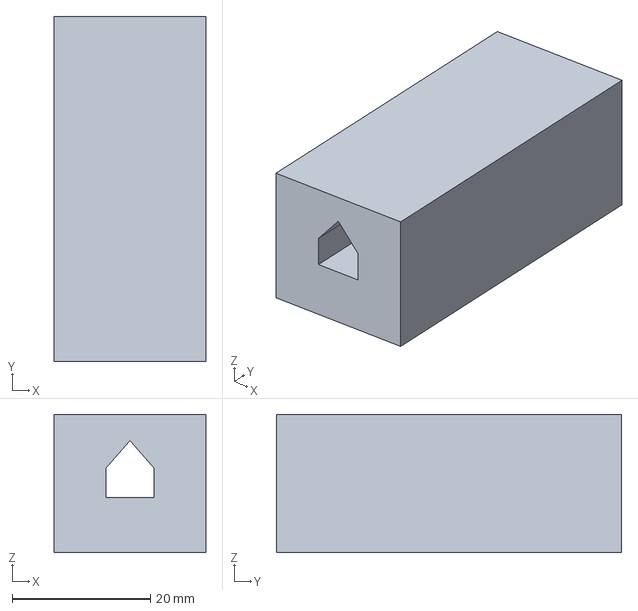
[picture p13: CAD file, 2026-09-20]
cad/retainer_coupons/STEP/retainer_coupon_base_receiver.step
22.0 x 50.0 x 20.0 mm

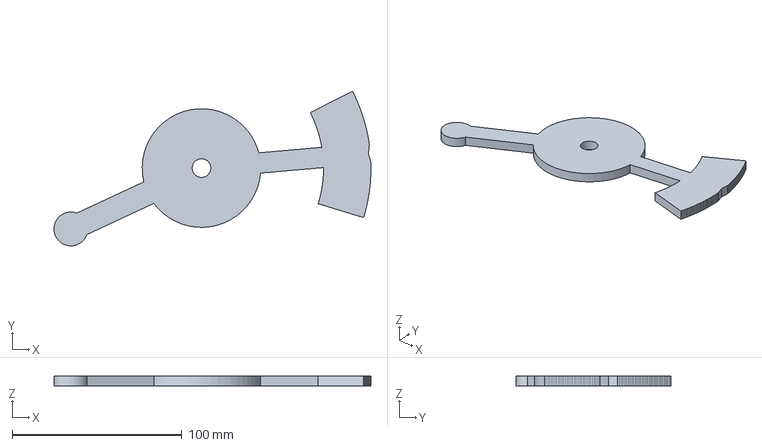
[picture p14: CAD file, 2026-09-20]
cad/detent_coupon/STEP/detent_coupon_cam.step
187.0 x 91.3 x 6.00 mm

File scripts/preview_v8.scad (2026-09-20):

// Samsung_Stand v8 retention preview.
// Replacement lock pins are rendered lighter than structural parts.

$fn=140;
pivot_y=-64;
right_angle=26.346366;
left_angle=153.653634;
inner_r0=85;
outer_r0=310;
inner_pin_r=60;
outer_pin_r=288;

module base() {
  color([0.20,0.20,0.22])
    import("../build_v8/samsung_stand_v8_base_center.stl",convexity=40);
  color([0.23,0.23,0.25])
    import("../build_v8/samsung_stand_v8_base_left.stl",convexity=40);
  color([0.23,0.23,0.25])
    import("../build_v8/samsung_stand_v8_base_right.stl",convexity=40);
}

module radial_part(file,r,a,z,c=[0.10,0.10,0.12]) {
  color(c)
    translate([0,pivot_y,z])
      rotate([0,0,a])
        translate([r,0,0])
          import(file,convexity=30);
}

module base_pin(x,y) {
  color([0.62,0.62,0.66])
    if (y < 0)
      translate([x,y-26,8.25])
        rotate([0,0,90])
          import("../build_v8/samsung_stand_v8_joint_lock_pin.stl",convexity=20);
    else
      translate([x,y+26,8.25])
        rotate([0,0,-90])
          import("../build_v8/samsung_stand_v8_joint_lock_pin.stl",convexity=20);
}

module inner_pin(a) {
  color([0.62,0.62,0.66])
    translate([0,pivot_y,0])
      rotate([0,0,a])
        translate([inner_pin_r,-23,19.25])
          rotate([0,0,90])
            import("../build_v8/samsung_stand_v8_joint_lock_pin.stl",convexity=20);
}

module outer_pin(a) {
  color([0.70,0.70,0.73])
    translate([0,pivot_y,0])
      rotate([0,0,a])
        translate([outer_pin_r,-32,22.25])
          rotate([0,0,90])
            import("../build_v8/samsung_stand_v8_outer_lock_pin.stl",convexity=20);
}

base();

color([0.55,0.55,0.58])
  translate([0,pivot_y,8.8])
    import("../build_v8/samsung_stand_v8_center_wear_ring.stl",convexity=30);

color([0.08,0.08,0.10])
  translate([0,0,10])
    import("../build_v8/samsung_stand_v8_rotor.stl",convexity=40);

radial_part("../build_v8/samsung_stand_v8_inner_arm.stl",inner_r0,right_angle,18);
radial_part("../build_v8/samsung_stand_v8_inner_arm.stl",inner_r0,left_angle,18);
radial_part("../build_v8/samsung_stand_v8_outer_guide.stl",outer_r0,right_angle,18,[0.16,0.16,0.18]);
radial_part("../build_v8/samsung_stand_v8_outer_guide.stl",outer_r0,left_angle,18,[0.16,0.16,0.18]);

base_pin(-100,-90);
base_pin(-100,90);
base_pin(100,-90);
base_pin(100,90);

inner_pin(right_angle);
inner_pin(left_angle);
outer_pin(right_angle);
outer_pin(left_angle);

color([0.78,0.78,0.81])
  translate([-18,pivot_y,21.7])
    import("../build_v8/samsung_stand_v8_pivot_lock_pin.stl",convexity=20);

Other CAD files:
cad/detent_coupon/STEP/detent_coupon_cassette_t18.step
cad/v8/STEP/samsung_stand_v8_detent_pin.step
cad/fit_coupons/STEP/fit_inner_receiver_c050.step
cad/v8/STEP/samsung_stand_v8_base_left.step
scripts/preview_v1.scad
scripts/preview_v2.scad
scripts/preview_v3.scad
cad/detent_coupon/FCStd/detent_coupon_base.FCStd
cad/detent_coupon/FCStd/detent_coupon_cam.FCStd
cad/detent_coupon/FCStd/detent_coupon_cassette_t18.FCStd
cad/detent_coupon/FCStd/detent_coupon_cassette_t22.FCStd
cad/detent_coupon/FCStd/detent_coupon_cassette_t26.FCStd
cad/detent_coupon/FCStd/detent_coupon_pin.FCStd
cad/detent_coupon/STEP/detent_coupon_cassette_t26.step
cad/detent_coupon/STL/detent_coupon_base.stl
cad/detent_coupon/STL/detent_coupon_cam.stl
cad/detent_coupon/STL/detent_coupon_cassette_t18.stl
cad/detent_coupon/STL/detent_coupon_cassette_t22.stl
cad/detent_coupon/STL/detent_coupon_cassette_t26.stl
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

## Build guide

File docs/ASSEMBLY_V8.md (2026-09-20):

# V8 assembly sequence

> Status: geometry-candidate assembly sequence. Do not mount the television until
> all applicable gates in `PHYSICAL_RELEASE_GATES.md` have passed.

## Before the large prints

Print and physically evaluate:

1. roof-key fit coupons;
2. v8 retainer coupons;
3. zero-detent calibration rig;
4. final measured Samsung contact inserts / liners when available.

Use the same printer, PETG, nozzle, layer height and relevant slicer settings
planned for the structural parts.

## Printed structural quantities

Core v8:

- 1 × BASE_CENTER
- 1 × BASE_LEFT
- 1 × BASE_RIGHT
- 1 × ROTOR
- 2 × INNER_ARM
- 2 × OUTER_GUIDE
- 1 × center wear ring
- 2 × side-track wear arcs
- 6 × compact joint lock pins
  - 4 for BASE ↔ CENTER
  - 2 for ROTOR ↔ INNER_ARM
- 2 × long OUTER lock pins
- 1 × pivot lock pin
- 2 × detent pins
- 1 × selected detent cassette
- 2 × measured saddle inserts
- 4 × measured OUTER_GUIDE side rails (2 per guide)

The legacy vertical base retainers, legacy pivot C-clip and legacy v2 arm lock
pin are not part of the v8 assembly.

## 1. Assemble the fixed base

1. Inspect all roof keys and receivers for elephant-foot, stringing or damaged
   snap surfaces.
2. Slide BASE_LEFT and BASE_RIGHT into BASE_CENTER through the long form-locking
   roof-key joints. Do not hammer the parts together.
3. Verify all three base modules sit on one common underside plane.
4. Install the four horizontal compact lock pins.

The front and rear pins are deliberately mirrored:

- rear joint at y = -90 mm: pin shaft runs toward +Y;
- front joint at y = +90 mm: pin shaft runs toward -Y.

This keeps the expanded snap barbs clear of the asymmetric center-base
reinforcement ribs.

The pins retain the joint against withdrawal. The roof-key overlap remains the
primary structural load path.

## 2. Install replaceable wear surfaces

1. Drop the center wear ring into the shallow annular BASE_CENTER recess.
2. Install one side-track wear arc in BASE_LEFT and one in BASE_RIGHT.
3. Verify all wear pieces sit fully down in their recesses without rocking.

Installed top planes must remain:

- center wear ring: z = 10 mm;
- side wear arcs: z = 18 mm.

Do not glue the wear pieces during fit validation. They are intended to remain
replaceable.

## 3. Install and calibrate the zero detent

1. Install the physically selected detent cassette on the fixed base.
2. Retain it with the two detent pins.
3. Verify the spring nose moves freely and is not pre-whitened.

The detent is positional only. It is not an end stop.

## 4. Place the rotor

1. Lower ROTOR over the extended central pivot post.
2. Seat it on the center wear ring.
3. Verify it rotates freely through the available range before installing the
   remaining rotating carrier parts.
4. Confirm the open central counterbore is accessible from above.

## 5. Install the pivot cross-pin

This step must occur before the INNER_ARM parts obstruct access to the central
assembly area.

1. Place the pivot lock pin horizontally into the top-open Ø61 mm rotor
   counterbore.
2. Align it with the support-friendly transverse tunnel in the fixed Ø25 mm
   pivot post.
3. Slide the pin through the post until the split-end barbs have passed the far
   side and expanded.
4. Verify the pin head and barb ends remain fully inside the circular rotor
   counterbore.
5. Rotate the rotor gently through the complete +/-15 degree range.

The rotor intentionally has approximately 0.7 mm axial lift clearance before
its counterbore shoulder reaches the fixed cross-pin. The pin is an accidental
lift retainer; normal TV weight is carried by the annular wear ring and the two
side-track supports, not by the pivot pin.

## 6. Install INNER_ARM left/right

For each side:

1. slide the inward roof key into the rotor receiver;
2. seat the flat root landing on the rotor support plane;
3. verify the outer saddle region simultaneously sits on the appropriate side
   wear arc;
4. insert one compact joint lock pin transversely through the rotor receiver and
   INNER_ARM tongue.

The lock pin retains withdrawal. It is not the primary bending support.

## 7. Install OUTER_GUIDE left/right

For each side:

1. slide the OUTER_GUIDE male roof key into the INNER_ARM receiver;
2. verify the U-guide remains clear of the fixed base;
3. insert the long v8 outer lock pin through the fully opened transverse tunnel.

V8 intentionally re-opens this tunnel through the complete 58 mm saddle region.
The earlier 50 mm tunnel was geometrically enclosed by the saddle and was not a
satisfactory real insertion path.

## 8. Install measured saddle contact parts

Only use contact parts generated from validated physical measurements.

1. place the left/right measured saddle inserts in the INNER_ARM pockets;
2. verify both inserts sit fully in their pockets without rocking or forcing an
   INNER_ARM out of its validated position.

Do **not** install the OUTER_GUIDE side rails yet. They are deliberately separate
lateral-only rails and are installed around the real stand arm in the next step.
Reconstructed stand dimensions are not a substitute for these measurements.

## 9. Dry-fit the original Samsung stand and install lateral guide rails

Before adding the television:

1. place the original Samsung stand in the two measured saddle inserts;
2. for each OUTER_GUIDE, slide the measured negative-Y and positive-Y side rail
   down from above between the Samsung arm and the corresponding guide wall;
3. verify all four side rails sit on the guide floor and remain on their own
   side of the arm centerline;
4. verify the arm is not vertically supported by any side rail. The generated
   V6 validation report must show at least 5 mm measured vertical clearance from
   every root/mid/tip cross-section to the structural OUTER_GUIDE floor;
5. rotate slowly from center to -15 degrees and +15 degrees;
6. verify:
   - vertical load remains on the inner supports;
   - outer guides and measured side rails only guide laterally;
   - positive mechanical end stops engage at +/-15 degrees;
   - the fixed base does not move on the Sounddeck;
   - no retainer walks out;
   - no PETG whitening appears.

## 10. Physical release testing

Proceed with a non-fragile substitute load, not the TV, and complete
`PHYSICAL_RELEASE_GATES.md`.

Only after measurement validation, fit coupons, static proof loading, creep
dwell, swivel/end-stop cycling and the Sounddeck anti-slip/surface gate have
passed should the real TV be mounted.

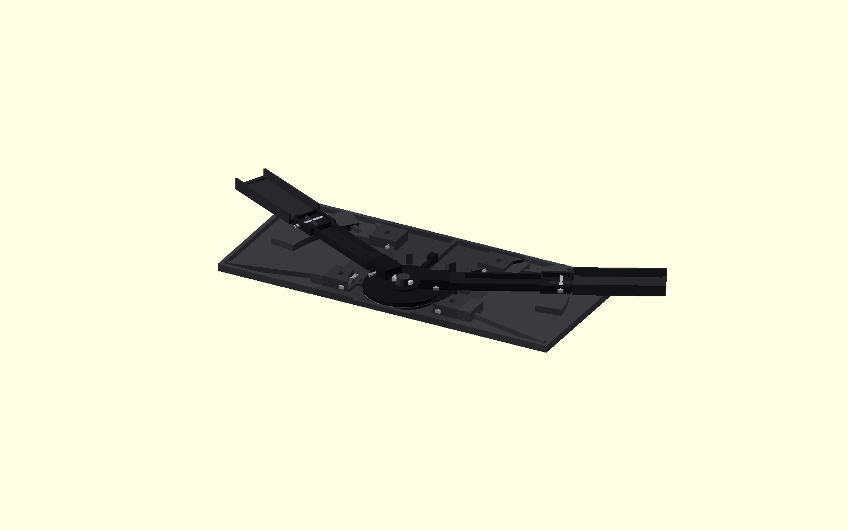
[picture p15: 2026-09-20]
cad/v8/assembly/samsung_stand_v8_preview.png

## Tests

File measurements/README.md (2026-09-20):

# Physical measurement input

This folder is the hand-off between the validated structural CAD and the real Samsung stand.

Do **not** fill missing values by estimation.

## Workflow

1. Copy `measurements/stand_measurements.template.json` to `measurements/stand_measurements.json`.
2. Keep `meta.measurement_kind = "physical"` and fill in the real measurer,
   ISO date and caliper resolution. Synthetic fixtures are rejected by the
   production workflow.
3. Enter measured global dimensions.
4. For each side of the inner saddle, measure **three sections** across the
   insert span: `root`, `center`, and `tip`. At every section record
   `center_xy_mm`, `lowest_point_height_mm`, and a 2D cross-section polygon
   looking along the stand arm axis.
5. For each outer-guide station (root/mid/tip), record the same three things:
   `center_xy_mm`, `lowest_point_height_mm`, and the measured cross-section
   polygon.
6. Run `python scripts/validate_measurements.py --require-physical measurements/stand_measurements.json`.
7. Only a complete, plausible **physical** measurement set unlocks the production v6 contact-part generator.

## Cross-section coordinates

Each `profile_points_mm` array contains points `[y,z]` in millimetres:

- y = lateral across the stand arm, with **y = 0 on the local arm centerline**;
- z = upward from the lowest physical point of that local cross-section;
- points ordered around the outside contour;
- no repeated final point is required;
- use enough points to represent radii/chamfers/ribs that matter for contact.

The profile is the **physical Samsung arm**, not desired clearance.

The CAD generator applies its own explicit geometric clearance. The current
project is PETG-only: `contact_pad.used` must remain `false` and compressed
pad thickness must remain `0.0`.

## Station center coordinates

Each measured station also contains `center_xy_mm: [x,y]`.

Use the swivel pivot as the origin:

- +X = right side of the television/stand;
- -X = left side;
- +Y = toward the front stand tips;
- values describe the center of the measured arm cross-section.

`station_radius_mm` is retained as an independent cross-check. The validator
rejects a radius that disagrees with `center_xy_mm` by more than 1.5 mm.

The generator projects these coordinates into the fixed v8 arm frames. Small
real lateral deviations therefore modify only the replaceable saddle inserts
and guide rails. They do **not** silently move the structural v8 arms.

## Common vertical datum

Every station requires `lowest_point_height_mm`.

Use one **unchanged flat reference plane for the complete stand**. The value is
the vertical distance from that plane to the lowest physical point of the
cross-section at the measurement station.

This is different from the local polygon coordinate:

- `profile_points_mm[*][1]` uses local z with the lowest point of that
  individual cross-section normalized to z = 0;
- `lowest_point_height_mm` says where that local z = 0 actually lies relative
  to the common reference plane.

Do not re-zero the height gauge separately at each station. Doing so would erase
the longitudinal rise/fall of the real Samsung arm and could hide an unintended
OUTER_GUIDE floor contact.

The generator uses the mean of the two **center** saddle-section
`lowest_point_height_mm` values as the vertical reference. The complete
root/center/tip saddle loft preserves measured relative height, lateral offset
and cross-section shape along the insert. Every outer-guide station is likewise
checked at its own measured relative Z position.

## Provenance gate

The metadata is part of the manufacturing input, not documentation only.

Required fields include:

- `measurement_kind`: `physical` for production or `synthetic` for CI only;
- `model`: exactly `Samsung UE55J6250`;
- `stand_part`: currently accepted `BN96-38964A`;
- `measured_by`: non-empty;
- `date`: ISO `YYYY-MM-DD`;
- `caliper_resolution_mm`: positive and no worse than 0.2 mm.

A synthetic file can still exercise the CAD pipeline, but it cannot pass the
production provenance gate or the production builder.

## Saddle sampling density

For the load-bearing saddle, root/center/tip are not merely labels. After
projection into the structural arm frame, adjacent measured sections may be no
more than **25 mm apart**, and the nearest root/tip section may be no more than
**8 mm** from the corresponding insert end.

These gates limit how much of the load-bearing insert is based on interpolation.
They do not replace the physical dry-fit check between stations.

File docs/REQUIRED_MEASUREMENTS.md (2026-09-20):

# Required physical Samsung stand measurements

The structural geometry is now isolated from the still-unverified Samsung contact
geometry.  The remaining measurements should therefore change only small contact
parts, not the complete load-bearing adapter.

Use a digital caliper where practical.  Record actual values rather than rounded
nominal guesses.  Photos with a ruler/caliper in the frame are useful for
cross-checking interpretation.

## A. Global stand geometry

Record with the original stand assembled exactly as it will be used:

- total left-to-right stand width;
- total front-to-back stand depth;
- pivot / neck center to rear-most contour;
- pivot / neck center to both front stand tips;
- X/Y location of both stand tips relative to the pivot;
- whether left and right geometry is measurably symmetric.

These measurements verify the reconstructed 840 mm / ~288–290 mm planform and
the current (0, -64 mm) swivel-axis placement.

## B. Inner saddle region

The replaceable saddle insert spans about 49 mm along each arm. One center
cross-section is not enough to prove the complete contact surface.

For **both left and right arms**, measure three cross-sections:

1. **root** — near the inboard end of the insert;
2. **center** — near the current support orbit at approximately 279 mm radius;
3. **tip** — near the outboard end of the insert.

At every root/center/tip section record:

- `station_radius_mm` from the swivel pivot;
- `center_xy_mm` relative to the swivel pivot;
- `lowest_point_height_mm` from one unchanged common flat reference plane;
- the complete `profile_points_mm` cross-section polygon;
- relevant radii/chamfers, ribs, bosses or protrusions.

The root and tip sections should be measured close enough to the insert ends
that only a short bounded extrapolation remains. The generator rejects a nearest
measured saddle section more than 8 mm from the corresponding insert end and
rejects adjacent measured saddle sections more than 25 mm apart.

Use photographs looking along the arm axis at all three sections where possible.
The generated saddle insert is a loft through the measured sections; the
INNER_ARM structural part remains unchanged.

## C. Outer guide region

The OUTER_GUIDE starts at about 310 mm radius and extends outward about 170 mm.
The current inside channel is deliberately oversized.

Measure the arm at three stations per side:

1. near the outer-guide root;
2. near the middle;
3. near the stand tip.

At every station record the cross-section polygon, its `center_xy_mm`
relative to the swivel pivot, and `lowest_point_height_mm` from the same
common flat reference plane used for the inner saddle measurements. This allows
the contact parts to follow both plan-view centerline deviations and real
vertical rise/fall of the arm.

Also record:

- taper in plan view;
- taper in height;
- side-wall angle;
- corner radii/chamfers;
- any local protrusions;
- whether a constant shim profile is possible or a tapered shim is required.

Preferred design outcome: keep the structural OUTER_GUIDE and generate small
replaceable side-contact shims/inserts instead of reprinting the 215 mm rail.

## D. Contact material / protection

Current project constraint: **all contact parts remain PETG-only**.

The original Samsung stand therefore touches printed PETG directly. External
protective pads, foam, TPU, rubber or adhesive layers are not part of the current
design and are rejected by the measurement validator.

Keep:

- `contact_pad.used = false`
- `contact_pad.compressed_thickness_mm = 0.0`

If this constraint is ever changed deliberately, the measurement schema,
generator and physical-release gates must be revised together rather than
silently adding another material.

## E. Values to return to CAD

Use **only** the canonical template:

`measurements/stand_measurements.template.json`

Copy it to:

`measurements/stand_measurements.json`

The current generator does **not** accept width/height-only approximations for
the Samsung contact geometry. Each relevant cross-section must be represented by
`profile_points_mm` as an ordered polygon of `[y,z]` points.

Minimal structural form:

```json
{
  "meta": {
    "measurement_kind": "physical",
    "model": "Samsung UE55J6250",
    "stand_part": "BN96-38964A",
    "measured_by": null,
    "date": null,
    "caliper_resolution_mm": null
  },
  "global": {
    "stand_width_mm": null,
    "stand_depth_mm": null,
    "pivot_to_rear_mm": null,
    "left_tip_xy_mm": [null, null],
    "right_tip_xy_mm": [null, null]
  },
  "inner_saddle": {
    "left": {
      "root": {
        "station_radius_mm": null,
        "center_xy_mm": [null, null],
        "lowest_point_height_mm": null,
        "profile_points_mm": null
      },
      "center": {
        "station_radius_mm": null,
        "center_xy_mm": [null, null],
        "lowest_point_height_mm": null,
        "profile_points_mm": null
      },
      "tip": {
        "station_radius_mm": null,
        "center_xy_mm": [null, null],
        "lowest_point_height_mm": null,
        "profile_points_mm": null
      }
    },
    "right": {
      "root": {
        "station_radius_mm": null,
        "center_xy_mm": [null, null],
        "lowest_point_height_mm": null,
        "profile_points_mm": null
      },
      "center": {
        "station_radius_mm": null,
        "center_xy_mm": [null, null],
        "lowest_point_height_mm": null,
        "profile_points_mm": null
      },
      "tip": {
        "station_radius_mm": null,
        "center_xy_mm": [null, null],
        "lowest_point_height_mm": null,
        "profile_points_mm": null
      }
    }
  },
  "outer_guide": {
    "left": {
      "root": {
        "station_radius_mm": null,
        "center_xy_mm": [null, null],
        "lowest_point_height_mm": null,
        "profile_points_mm": null
      },
      "mid": {
        "station_radius_mm": null,
        "center_xy_mm": [null, null],
        "lowest_point_height_mm": null,
        "profile_points_mm": null
      },
      "tip": {
        "station_radius_mm": null,
        "center_xy_mm": [null, null],
        "lowest_point_height_mm": null,
        "profile_points_mm": null
      }
    },
    "right": {
      "root": {
        "station_radius_mm": null,
        "center_xy_mm": [null, null],
        "lowest_point_height_mm": null,
        "profile_points_mm": null
      },
      "mid": {
        "station_radius_mm": null,
        "center_xy_mm": [null, null],
        "lowest_point_height_mm": null,
        "profile_points_mm": null
      },
      "tip": {
        "station_radius_mm": null,
        "center_xy_mm": [null, null],
        "lowest_point_height_mm": null,
        "profile_points_mm": null
      }
    }
  },
  "contact_pad": {
    "used": false,
    "compressed_thickness_mm": 0.0
  }
}
```

Coordinate convention for every profile:

- `y = 0` is the local arm centerline;
- `z = 0` is the lowest physical point of that measured cross-section;
- points run around the complete outer contour;
- real kinks/chamfers/radii that affect fit must be represented rather than
  smoothed away.

The validator rejects incomplete, self-intersecting, off-center or implausible
profiles. Do not enter guessed values simply to make the record complete.

## F. Provenance

Production contact CAD is generated only from a file whose
`meta.measurement_kind` is `physical`. The CI fixture is explicitly marked
`synthetic` and is intentionally rejected when the validator is called with
`--require-physical`.

The model, accepted stand part, measurer, date and caliper resolution are also
validated. This prevents a geometrically plausible test fixture or measurement
set for a different stand from being silently published as manufacturing CAD.

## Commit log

2026-09-20 Fit swivel bearing to rear-offset center module
2026-09-20 Increase rear wall around swivel bearing
2026-09-20 Hard-gate rear bearing margin
2026-09-20 Build first modular PETG base and swivel CAD
2026-09-20 Add installed v1 preview
    [preview_v1.scad]
2026-09-20 Test v1 joints and rear-offset bearing
2026-09-20 Publish validated Samsung Stand v1 CAD
    [samsung_stand_v1_base_center.FCStd, samsung_stand_v1_base_center.step, samsung_stand_v1_base_center.stl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]
2026-09-20 Define v2 glide-track and inner-arm geometry
2026-09-20 Define replaceable snap cross-pin for rotor arms
2026-09-20 Validate support-free rotor arm lock
2026-09-20 Keep v2 arm lock pin flat-printable
2026-09-20 Add v2 mesh and print-envelope validation
2026-09-20 Add installed v2 support-path preview
    [preview_v2.scad]
2026-09-20 Publish validated Samsung Stand v2 CAD
    [samsung_stand_v2_arm_lock_pin.FCStd, samsung_stand_v2_arm_lock_pin.step, samsung_stand_v2_arm_lock_pin.stl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]
2026-09-20 Separate rotor root support from arm key guidance
2026-09-20 Add coplanar rotor root landings
2026-09-20 Add OCC installed-assembly validation for v2
2026-09-20 Clean v2 insert assembly transform
2026-09-20 Hard-gate installed v2 OCC assembly
2026-09-20 Run v2 OCC assembly validator through FreeCAD Python
2026-09-20 Keep radial pilot clearance inside rotor bore
2026-09-20 Clear fixed center ribs from v2 rotor sweep
2026-09-20 Hard-gate v2 rotor sweep clearance
2026-09-20 Build modular v3 outer guide rails
2026-09-20 Add v3 outer-guide assembly validation
2026-09-20 Add v3 outer-guide installed preview
    [preview_v3.scad]
2026-09-20 Publish validated Samsung Stand v3 CAD
    [samsung_stand_v3_arm_lock_pin.FCStd, samsung_stand_v3_arm_lock_pin.step, samsung_stand_v3_arm_lock_pin.stl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]
2026-09-20 Share exact v4 stop geometry between CAD and validation
2026-09-20 Prove exact v4 stop behavior with OCC assembly checks
2026-09-20 Make v4 stop flat-printable with fixed-base sweep clearance
2026-09-20 Cut support-free stop sweep corridor into v4 center base
2026-09-20 Add v4 mesh and print-envelope validation
2026-09-20 Add installed v4 stop preview
    [preview_v4.scad]
2026-09-20 Calibrate 15 degree stop and define arm sweep clearance
2026-09-20 Add exact inner-arm sweep clearance geometry
2026-09-20 Clear inherited side buttresses from inner-arm swivel sweep
2026-09-20 Hard-gate calibrated stop and side-buttress sweep clearance
2026-09-20 Publish validated Samsung Stand v4 CAD
    [samsung_stand_v4_arm_lock_pin.FCStd, samsung_stand_v4_arm_lock_pin.step, samsung_stand_v4_arm_lock_pin.stl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]
2026-09-20 Define replaceable zero-detent calibration cassette
2026-09-20 Give detent locating pins full cassette and mount engagement
2026-09-20 Add shared v5 detent track and cassette geometry
2026-09-20 Hard-gate v5 detent geometry and spring calibration range
2026-09-20 Overlap v5 detent mount into center base skin
2026-09-20 Cut v5 locating-pin blind holes after base fusion
2026-09-20 Build v5 replaceable zero-detent calibration cassette
2026-09-20 Expose v5 detent nose and spring body for independent OCC gates
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2026-09-20 Add v5 installed detent preview
    [preview_v5.scad]
2026-09-20 Publish validated Samsung Stand v5 CAD
    [samsung_stand_v5_arm_lock_pin.FCStd, samsung_stand_v5_arm_lock_pin.step, samsung_stand_v5_arm_lock_pin.stl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]
2026-09-20 Publish structural fit coupons
    [fit_base_male_probe.FCStd, fit_base_male_probe.step, fit_base_male_probe.stl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]
2026-09-20 Build measurement-driven v6 saddle inserts and guide liners
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2026-09-20 Publish zero-detent calibration rig
    [detent_coupon_base.FCStd, detent_coupon_base.step, detent_coupon_base.stl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]
2026-09-20 Validate v7 wear inserts through full support sweep
2026-09-20 Add v7 wear-surface assembly preview
    [preview_v7.scad]
2026-09-20 Publish validated Samsung Stand v7 CAD
    [samsung_stand_v7_arm_lock_pin.FCStd, samsung_stand_v7_arm_lock_pin.step, samsung_stand_v7_arm_lock_pin.stl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]
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2026-09-20 Make v8 pivot tunnel printable and outer lock externally accessible
2026-09-20 Add v8 accessible outer lock and robust pivot post fuse
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2026-09-20 Add v8 assembled retainer preview
    [preview_v8.scad]
2026-09-20 Open pivot counterbore for real top-down cross-pin assembly
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2026-09-20 Mirror front v8 base pins in assembly preview
    [preview_v8.scad]
2026-09-20 Publish v8 retainer fit coupons
    [retainer_coupon_base_receiver.FCStd, retainer_coupon_base_receiver.step, retainer_coupon_base_receiver.stl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]
2026-09-20 Start compact joint barb only after receiver exit
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2026-09-20 Cut local front-barb relief without enlarging base lock tunnel
2026-09-20 Publish validated Samsung Stand v8 CAD
    [samsung_stand_v8_base_center.FCStd, samsung_stand_v8_base_center.step, samsung_stand_v8_base_center.stl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]
2026-09-20 Document practical v8 assembly order and load-path intent
2026-09-20 Validate measured contact parts against current v8 structure
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2026-09-20 Publish v8 proof-load saddle fixture
    [proof_load_saddle_pad.FCStd, proof_load_saddle_pad.step, proof_load_saddle_pad.stl]
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2026-09-20 Update V8 assembly for four lateral-only measured guide rails
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2026-09-20 Project physical station centers into structural arm frames
2026-09-20 Fit measured contacts to physical arm centerline offsets
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2026-09-20 Hard-gate passive axial capture of measured guide rails
2026-09-20 Track structural parameter dependencies in V6 contact CI
2026-09-20 Make target printer and PETG canonical release parameters
2026-09-20 Bind physical release to target printer PETG and contact version
2026-09-20 Test printer material and contact-version release binding
2026-09-20 Exercise measured vertical arm profile offsets in V6 CI
2026-09-20 Validate measured vertical arm geometry against V8 contacts
2026-09-20 Use measured floor clearance in assembly checks
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
